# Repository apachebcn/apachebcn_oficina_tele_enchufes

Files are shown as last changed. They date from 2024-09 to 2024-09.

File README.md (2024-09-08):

# apachebcn_oficina_tele_enchufes

Control remoto de enchufes, pensado para la oficina para encender y apagar fácilmente todos los dispositivos.
Incluye proyecto de Kicad para fabricar las placas.

El proyecto consta de 2 placas pcbs.
1 pcb para conectar el arduino a los relés. (yo lo tengo debajo de la mesa, porque no es necesario tener acceso nivisibilidad a esta placa)
1 pcb de interfaz donde están los pulsadores para activar/desactivar los relés, y leds de testigos para saber que relés están encendidos.

Foto de pcb de la interfaz:

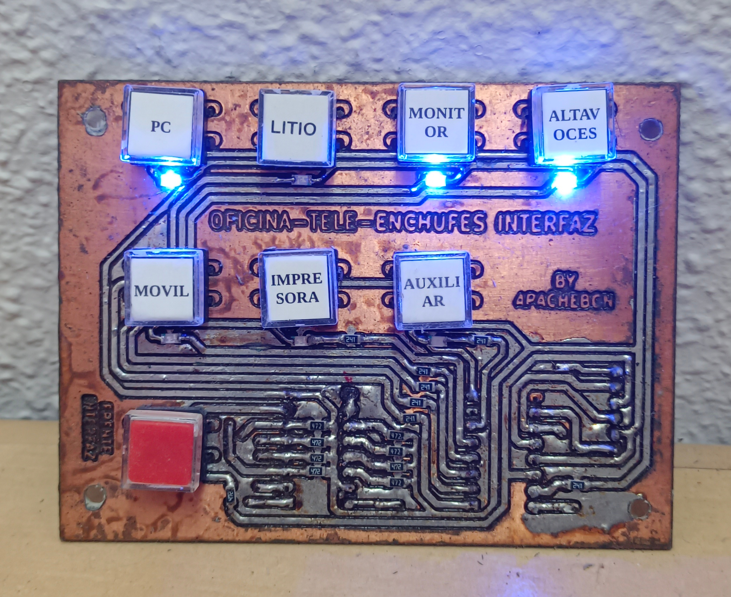
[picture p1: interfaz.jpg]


Foto de pcb de los relés:



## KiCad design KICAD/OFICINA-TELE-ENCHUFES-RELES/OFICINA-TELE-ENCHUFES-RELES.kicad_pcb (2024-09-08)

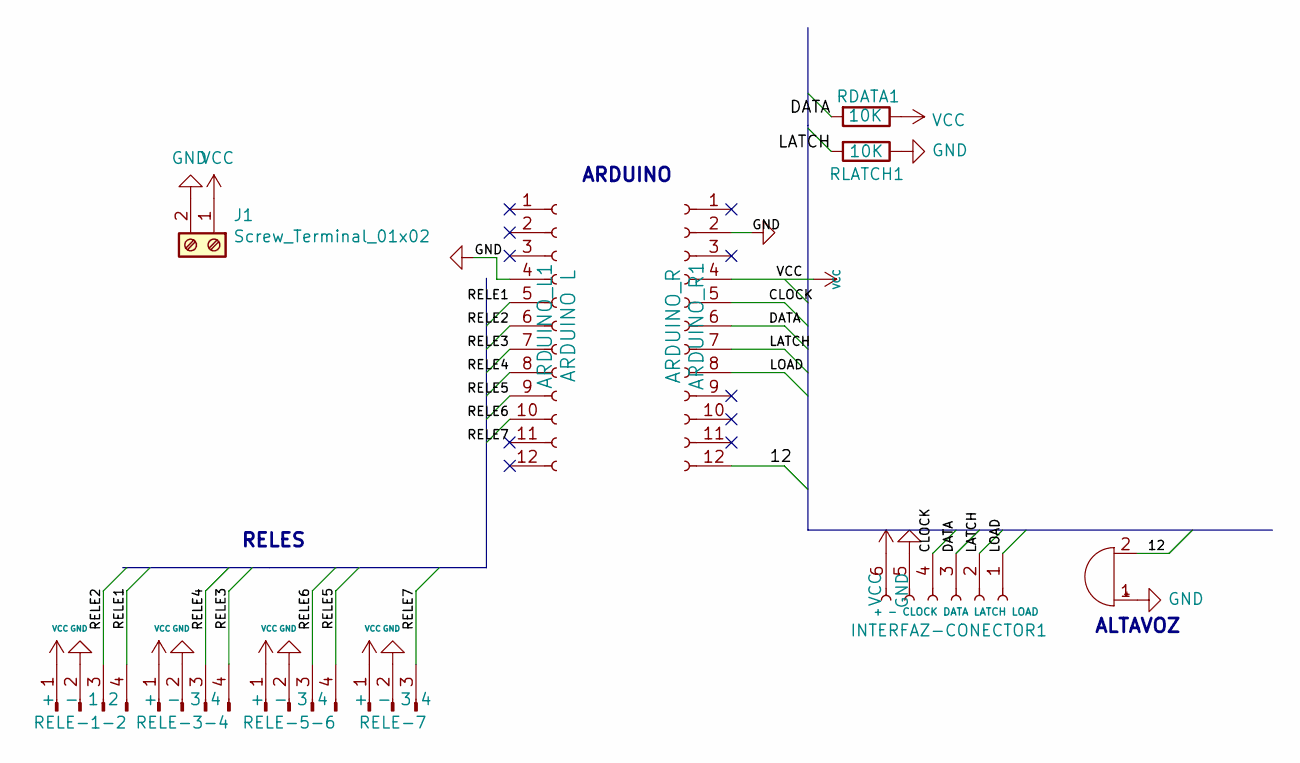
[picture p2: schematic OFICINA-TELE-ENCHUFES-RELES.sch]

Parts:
ARDUINO_L1: ARDUINO L; PinSocket_1x13_P2.54mm_Vertical
ARDUINO_R1: ARDUINO_R; PinSocket_1x13_P2.54mm_Vertical
BUZZER1: SPEAKER; Buzzer_12x9.5RM7.6
INTERFAZ-CONECTOR1: + - CLOCK DATA LATCH LOAD; JST_EH_B6B-EH-A_1x06_P2.50mm_Vertical
J1: Screw_Terminal_01x02; TerminalBlock_bornier-2_P5.08mm
RDATA1: 10K; R_1206_3216Metric
RELE-1-2: + - 1 2; PinHeader_1x04_P2.54mm_Horizontal
RELE-3-4, RELE-5-6: + - 3 4; PinHeader_1x04_P2.54mm_Horizontal
RELE-7: + - 3 4; PinHeader_1x03_P2.54mm_Horizontal
RLATCH1: 10K; R_1206_3216Metric

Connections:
/12: ARDUINO_R1.12, BUZZER1.2 (+)
/CLOCK: ARDUINO_R1.5, INTERFAZ-CONECTOR1.4
/DATA: ARDUINO_R1.6, INTERFAZ-CONECTOR1.3, RDATA1.2
/LATCH: ARDUINO_R1.7, INTERFAZ-CONECTOR1.2, RLATCH1.2
/LOAD: ARDUINO_R1.8, INTERFAZ-CONECTOR1.1
/RELE1: ARDUINO_L1.5, RELE-1-2.4
/RELE2: ARDUINO_L1.6, RELE-1-2.3
/RELE3: ARDUINO_L1.7, RELE-3-4.4
/RELE4: ARDUINO_L1.8, RELE-3-4.3
/RELE5: ARDUINO_L1.9, RELE-5-6.4
/RELE6: ARDUINO_L1.10, RELE-5-6.3
/RELE7: ARDUINO_L1.11, RELE-7.3
GND: ARDUINO_L1.4, ARDUINO_R1.2, BUZZER1.1 (-), INTERFAZ-CONECTOR1.5, J1.2, RELE-1-2.2, RELE-3-4.2, RELE-5-6.2, RELE-7.2, RLATCH1.1
VCC: ARDUINO_R1.4, INTERFAZ-CONECTOR1.6, J1.1, RDATA1.1, RELE-1-2.1, RELE-3-4.1, RELE-5-6.1, RELE-7.1

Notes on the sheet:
ALTAVOZ
RELES
ARDUINO

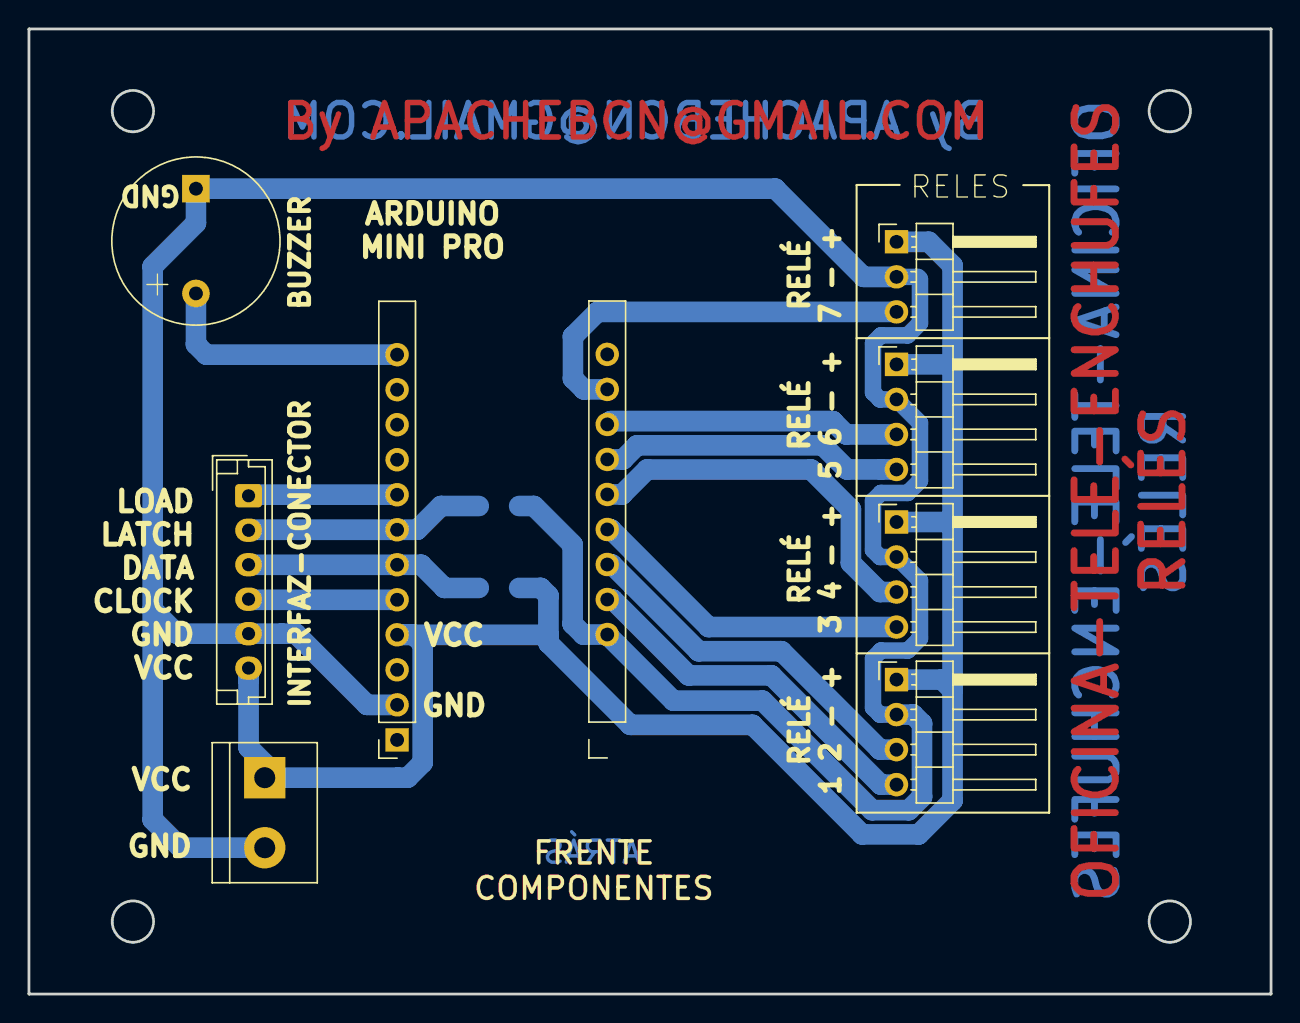
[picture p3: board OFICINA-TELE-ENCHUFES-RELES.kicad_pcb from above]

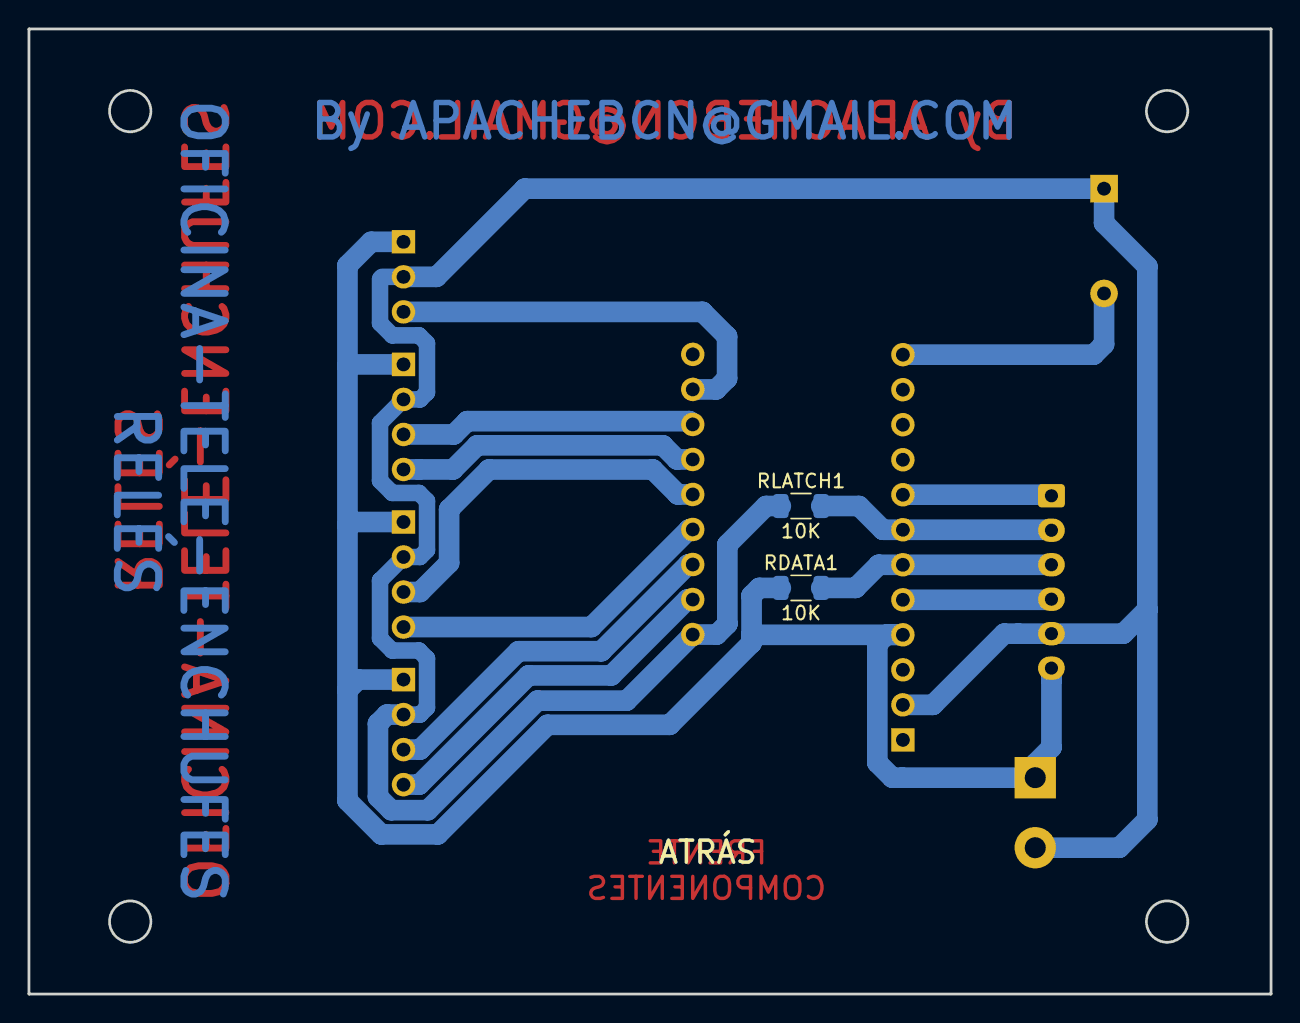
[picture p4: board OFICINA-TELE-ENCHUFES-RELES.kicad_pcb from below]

Board: 2 copper layers, 90.1 x 70.0 mm, 11 parts (2 on the bottom side), 14 nets.

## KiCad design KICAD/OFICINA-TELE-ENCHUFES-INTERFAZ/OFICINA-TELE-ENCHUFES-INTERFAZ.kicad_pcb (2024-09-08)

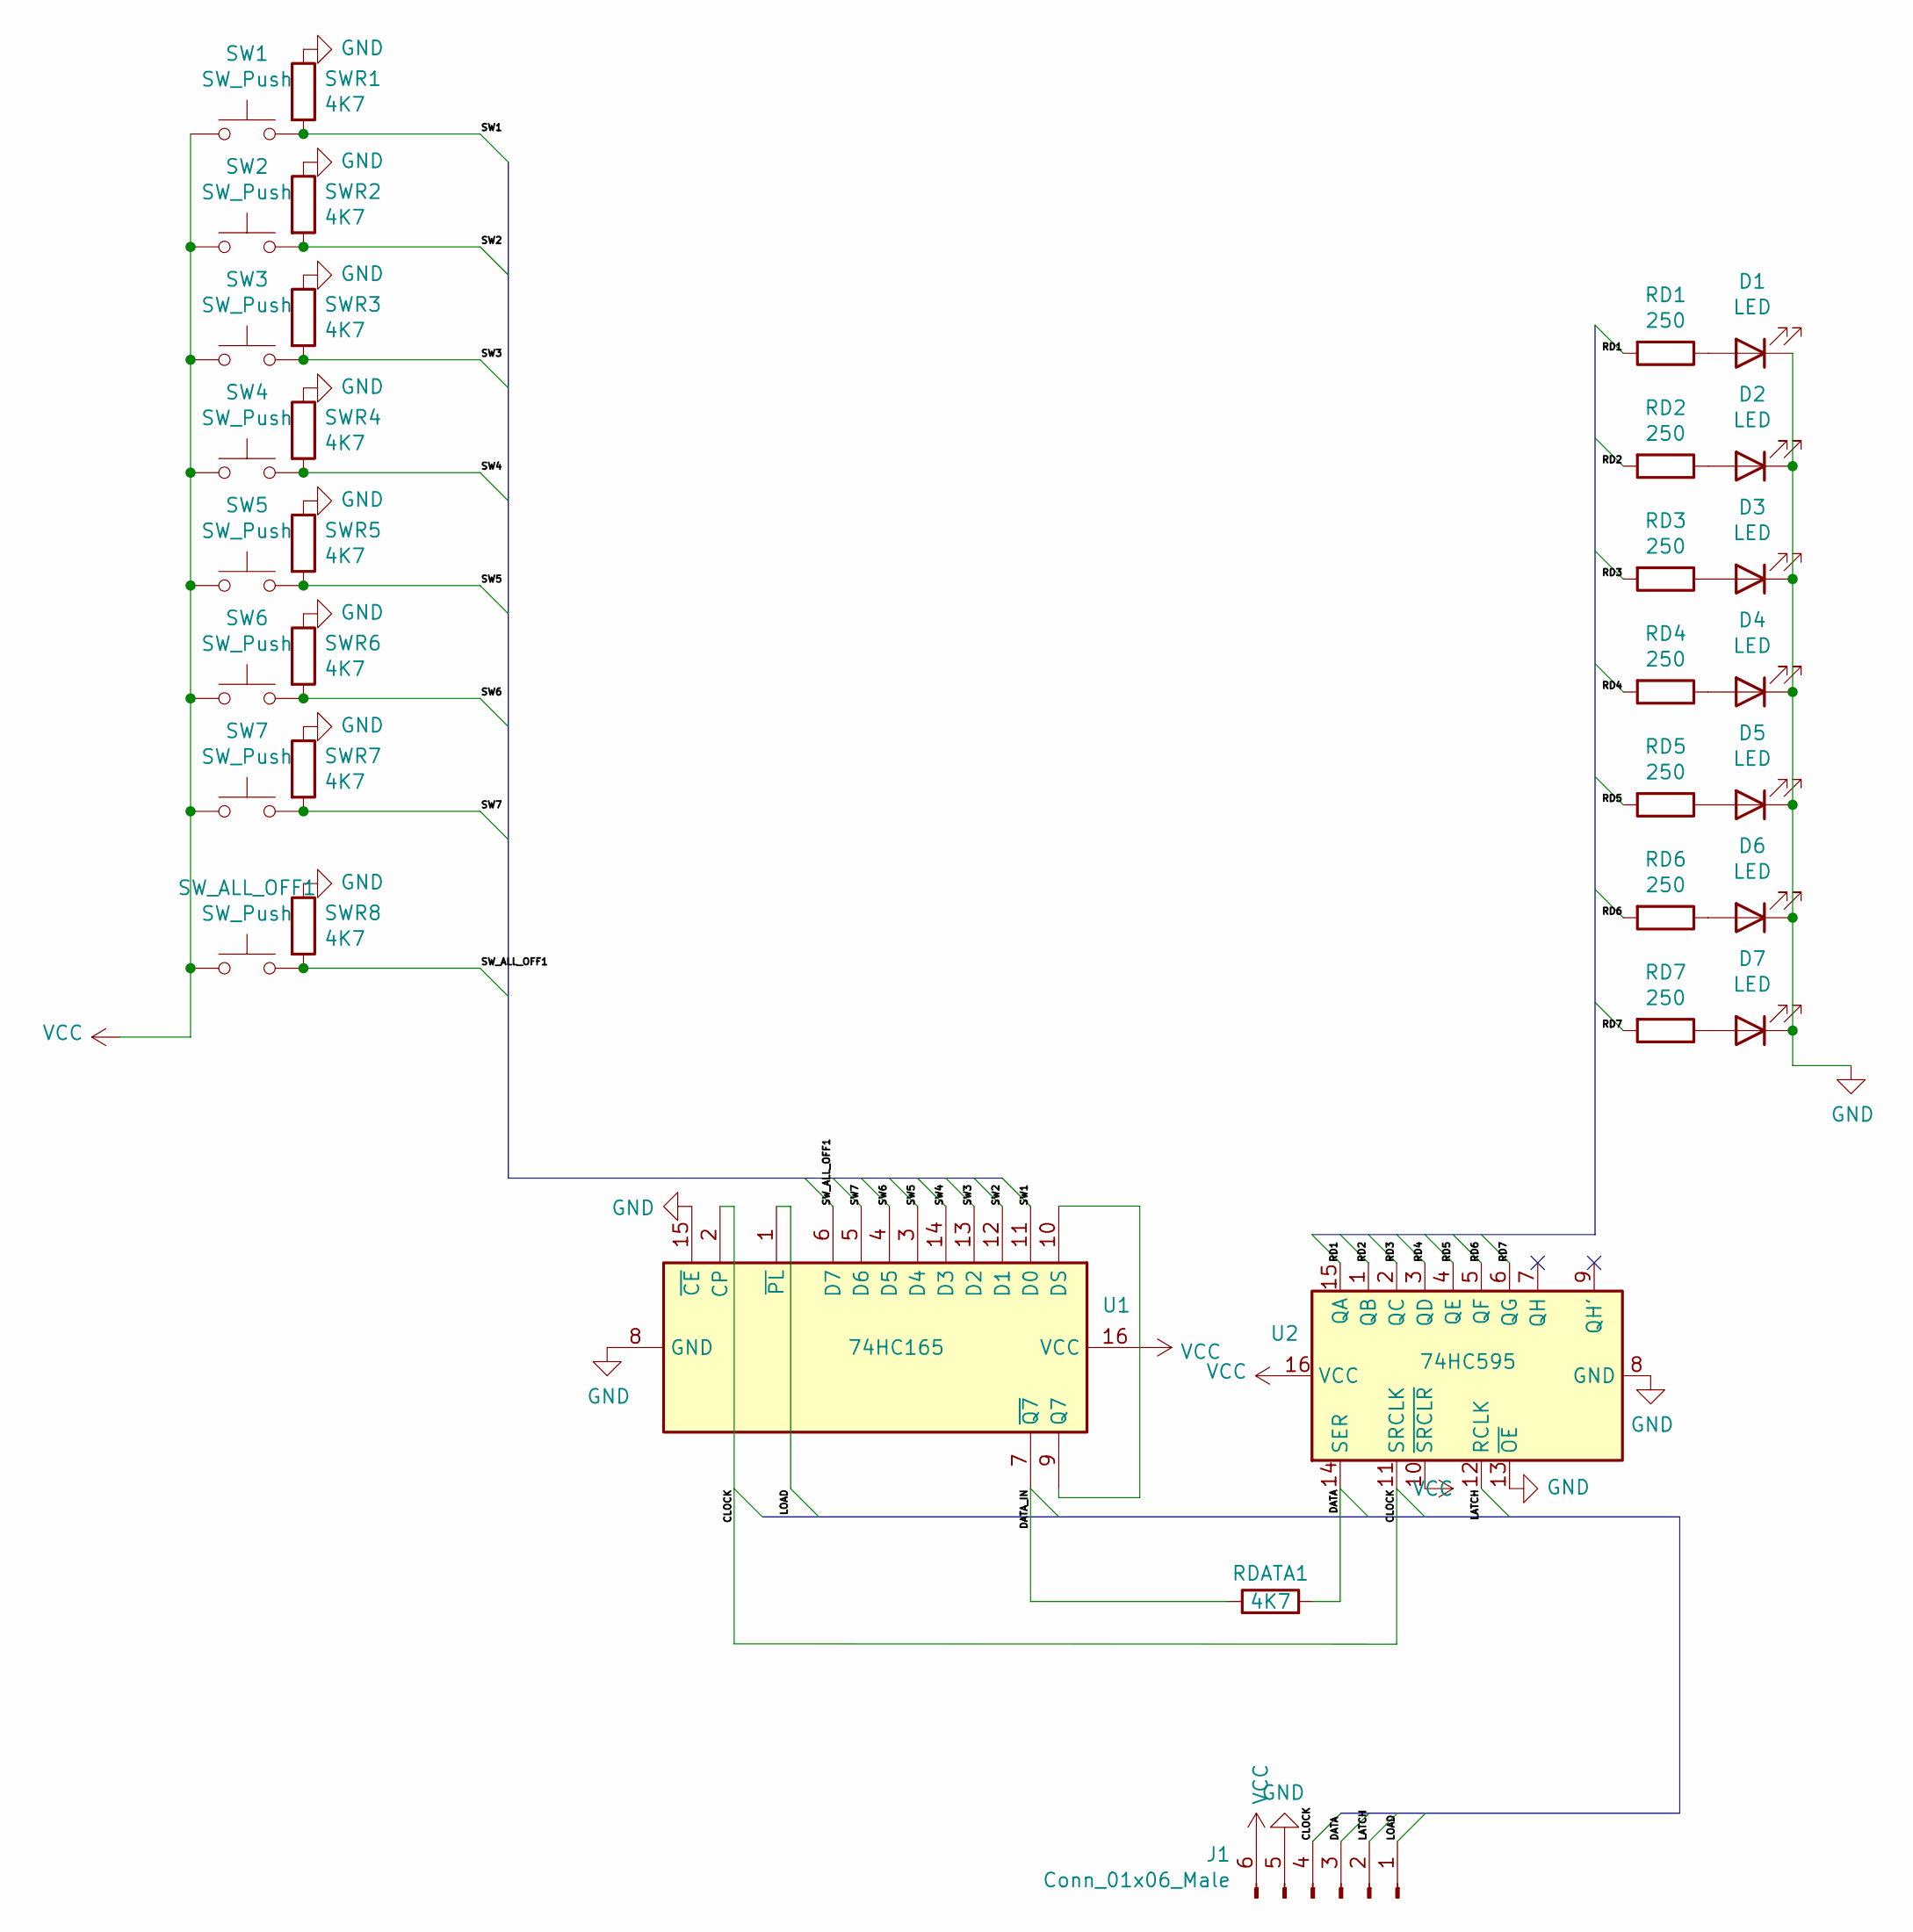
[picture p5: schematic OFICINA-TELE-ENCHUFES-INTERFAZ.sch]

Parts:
D1, D2, D3, D4, D5, D6, D7: LED; D_1206_3216Metric
J1: Conn_01x06_Male; JST_EH_B6B-EH-A_1x06_P2.50mm_Vertical
RD1, RD2, RD3, RD4, RD5, RD6, RD7: 250; R_1206_3216Metric
RDATA1: 4K7; R_1206_3216Metric
SW1, SW2, SW3, SW4, SW5, SW6, SW7: SW_Push; SW_PUSH-12mm
SWR1, SWR2, SWR3, SWR4, SWR5, SWR6, SWR7, SWR8: 4K7; R_1206_3216Metric
SW_ALL_OFF1: SW_Push; SW_PUSH-12mm
U1: 74HC165; DIP-16_W7.62mm
U2: 74HC595; DIP-16_W7.62mm

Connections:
/CLOCK: J1.4, U1.2 (CP), U2.11 (SRCLK)
/DATA: J1.3, RDATA1.2, U2.14 (SER)
/DATA_IN: RDATA1.1, U1.7 (~Q7)
/LATCH: J1.2, U2.12 (RCLK)
/LOAD: J1.1, U1.1 (~PL)
/RD1: RD1.2, U2.15 (QA)
/RD2: RD2.2, U2.1 (QB)
/RD3: RD3.2, U2.2 (QC)
/RD4: RD4.2, U2.3 (QD)
/RD5: RD5.2, U2.4 (QE)
/RD6: RD6.2, U2.5 (QF)
/RD7: RD7.2, U2.6 (QG)
/SW1: SW1.2, SWR1.2, U1.11 (D0)
/SW2: SW2.2, SWR2.2, U1.12 (D1)
/SW3: SW3.2, SWR3.2, U1.13 (D2)
/SW4: SW4.2, SWR4.2, U1.14 (D3)
/SW5: SW5.2, SWR5.2, U1.3 (D4)
/SW6: SW6.2, SWR6.2, U1.4 (D5)
/SW7: SW7.2, SWR7.2, U1.5 (D6)
/SW_ALL_OFF1: SWR8.2, SW_ALL_OFF1.2, U1.6 (D7)
GND: D1.1 (K), D2.1 (K), D3.1 (K), D4.1 (K), D5.1 (K), D6.1 (K), D7.1 (K), J1.5, SWR1.1, SWR2.1, SWR3.1, SWR4.1, SWR5.1, SWR6.1, SWR7.1, SWR8.1, U1.8 (GND), U1.15 (~CE), U2.8 (GND), U2.13 (~OE)
unnamed: D1.2 (A), RD1.1
unnamed: D2.2 (A), RD2.1
unnamed: D3.2 (A), RD3.1
unnamed: D4.2 (A), RD4.1
unnamed: D5.2 (A), RD5.1
unnamed: D6.2 (A), RD6.1
unnamed: D7.2 (A), RD7.1
unnamed: U1.9 (Q7), U1.10 (DS)
VCC: J1.6, SW1.1, SW2.1, SW3.1, SW4.1, SW5.1, SW6.1, SW7.1, SW_ALL_OFF1.1, U1.16 (VCC), U2.10 (~SRCLR), U2.16 (VCC)

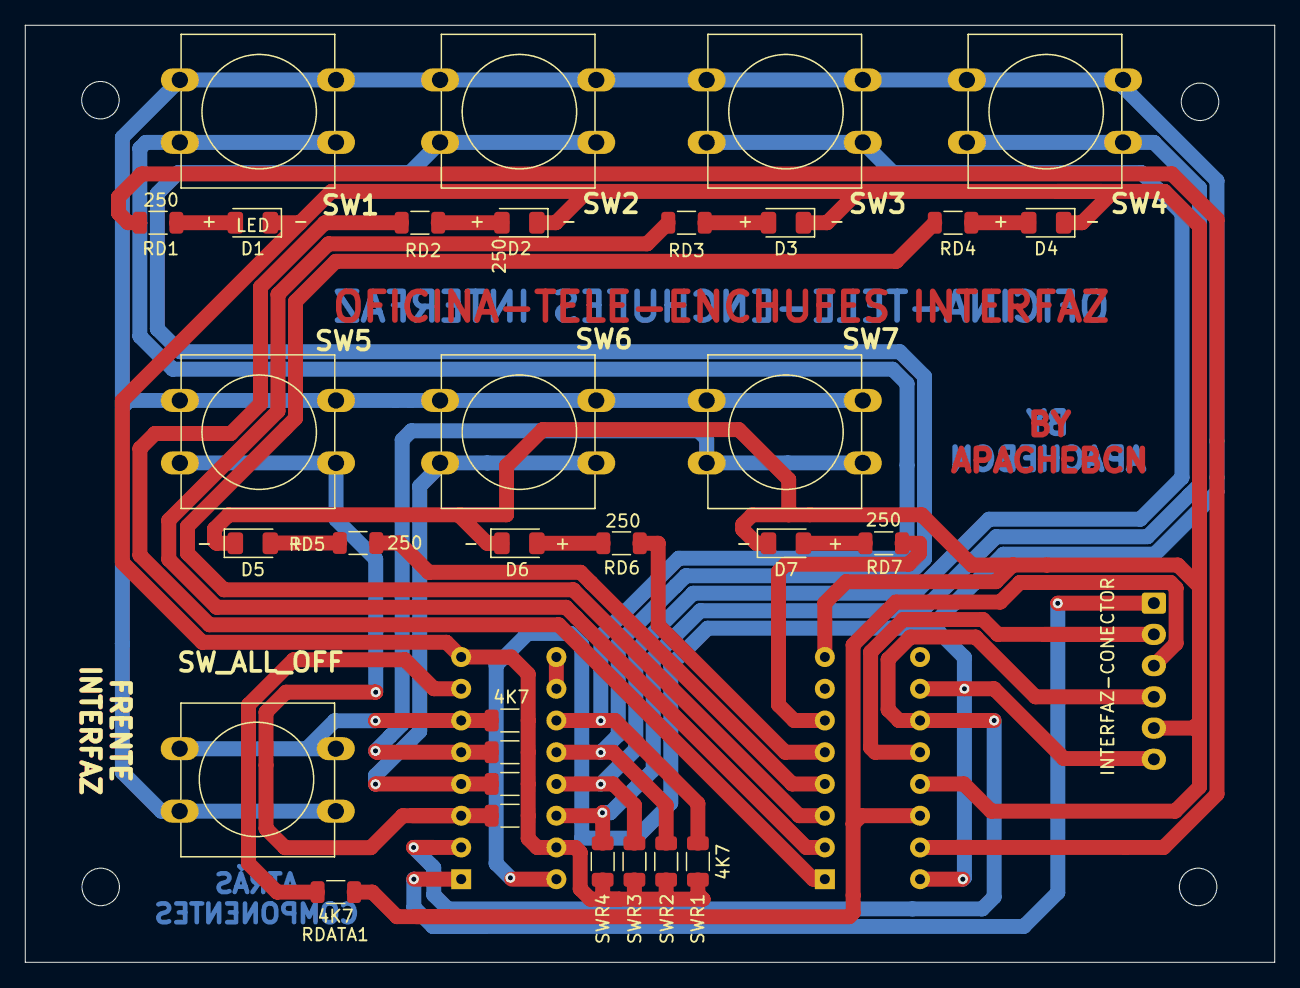
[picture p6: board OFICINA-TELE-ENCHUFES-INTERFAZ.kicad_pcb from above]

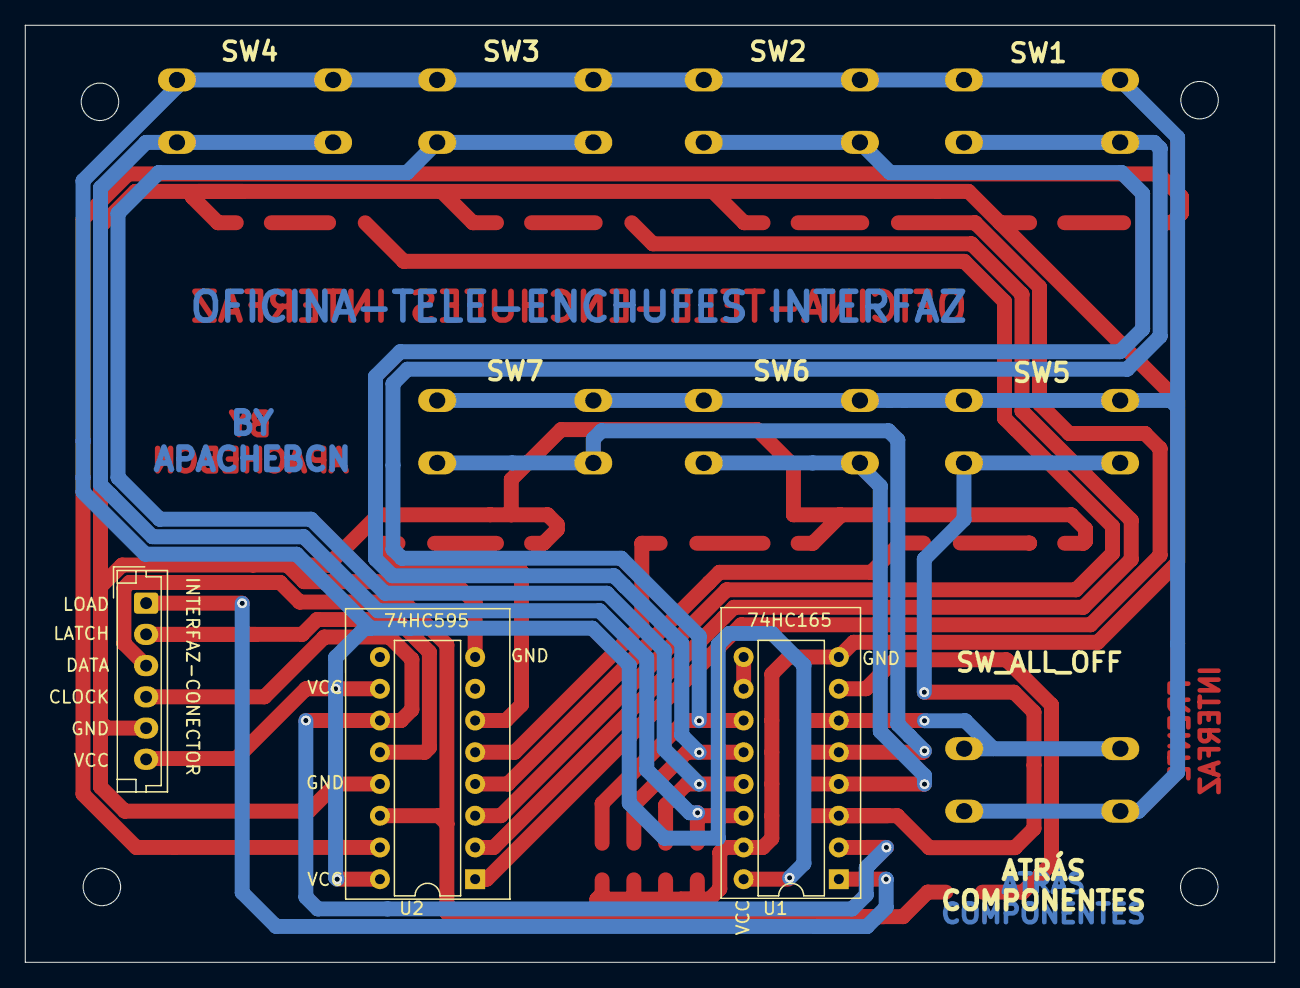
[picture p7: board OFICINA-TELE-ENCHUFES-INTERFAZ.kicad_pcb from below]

Board: 2 copper layers, 100.0 x 75.0 mm, 34 parts (3 on the bottom side), 30 nets.

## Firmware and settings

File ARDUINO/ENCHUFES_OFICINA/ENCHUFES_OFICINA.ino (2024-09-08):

// esquema aplicado: https://forums.parallax.com/uploads/attachments/43798/82270.jpg
//https://forums.parallax.com/discussion/133296/using-a-74hc165-and-a-74hc595-on-4-pins-spin


//poner en latch resistencia de 10Kohmls contra gnd


// Define Connections to 74HC595 

const int PIN_595_LATCH = A1;
/*
    74595 -> ST_CP pin 12
*/

const int PIN_595_AND_165_CLOCK = A3;
/*
    74595 -> SH_CP pin 11
    74165 -> CP pin 2
*/

const int PIN_595_AND_165_DATA = A2;
/*
    74595 -> DS pin 14 
    74165 -> Q7 pin 7
*/

// Define Connections to 74HC165
const int PIN_165_LOAD = A0;
/* 
    74165 -> PL pin 1
*/

const int PIN_RELES[8] = {2, 3, 4, 5, 6, 7, 8, 0};

byte buffer_leds[] = {0, 0, 0, 0, 0, 0, 0};
#define LAST_BIT_FOR_LEDS 7

unsigned long buffer_before_keys_timer[] = {0, 0, 0, 0, 0, 0, 0, 0};
byte buffer_before_keys[] = {0, 0, 0, 0, 0, 0, 0, 0};
byte buffer_keys[] = {0, 0, 0, 0, 0, 0, 0, 0};
#define LAST_BIT_FOR_KEYS 8

byte group_keys_from_key_0[] = {0, 2, 3}; // Para usar con Pc+Monitor+Altavoces
byte group_keys_from_key_1[] = {1, 2, 3}; // Para usar con Portatil+Monitor+Altavoces

const int PIN_BEEPER = 12;

void setup()
{
    pinMode(PIN_595_LATCH, OUTPUT);
    pinMode(PIN_165_LOAD, OUTPUT);
    pinMode(PIN_595_AND_165_CLOCK, OUTPUT);
    pinMode(PIN_595_AND_165_DATA, INPUT);
  
    digitalWrite(PIN_165_LOAD, HIGH);
    digitalWrite(PIN_595_AND_165_CLOCK, LOW);

    pinMode(PIN_BEEPER, OUTPUT);

    for(byte loop_byte_led = 0; loop_byte_led < LAST_BIT_FOR_LEDS; loop_byte_led++)
    {
        pinMode(PIN_RELES[loop_byte_led], OUTPUT); //Setea el pin de cada relé
        digitalWrite(PIN_RELES[loop_byte_led], 1); //Apaga el estado de cada relé para iniciar con todos apagados
    }

    // Serial.begin(115200);
    ledsTest();
}


void loop() 
{

    readKeys();
    // for (byte loop_byte_led=0; loop_byte_led < LAST_BIT_FOR_LEDS; loop_byte_led++)
    // {
        // buffer_leds[loop_byte_led] = buffer_keys[loop_byte_led];
        // Serial.print(buffer_keys[loop_byte_led]);
    // }
    // Serial.println();

    flushLeds();
    flushReles();

    for (byte loop_byte_key=0; loop_byte_key < LAST_BIT_FOR_KEYS; loop_byte_key++)
    {
        if (buffer_keys[loop_byte_key] == 1)
        {
            if (buffer_before_keys_timer[loop_byte_key] == 0) buffer_before_keys_timer[loop_byte_key] = millis();
        }
        else
        {
            if (buffer_before_keys[loop_byte_key] == 1 && buffer_keys[loop_byte_key] == 0)
            {
                if ((millis()-buffer_before_keys_timer[loop_byte_key]) > 400)
                {
                    if (key_long_action(loop_byte_key) == 1)
                    {
                        beep();
                        delay(100);
                        beep();
                    }
                }
                else
                {
                    if (key_action(loop_byte_key) == 1)
                    {
                        beep();
                    }
                }
                buffer_before_keys_timer[loop_byte_key] = 0;
            }
        }
        buffer_before_keys[loop_byte_key] = buffer_keys[loop_byte_key];
    }
}

void ledsTest()
{
    byte loop_byte_led = 0;
    byte led_byte_clear = 0;
    for(loop_byte_led = 0; loop_byte_led < LAST_BIT_FOR_LEDS; loop_byte_led++)
    {
        for (led_byte_clear = 0; led_byte_clear < LAST_BIT_FOR_LEDS; led_byte_clear++) { buffer_leds[led_byte_clear] = 0; }
        buffer_leds[loop_byte_led] = 1;
        flushLeds();
        beep();
    }
    for (led_byte_clear = 0; led_byte_clear < LAST_BIT_FOR_LEDS; led_byte_clear++) { buffer_leds[led_byte_clear] = 1; }
    for (led_byte_clear = 0; led_byte_clear < LAST_BIT_FOR_LEDS; led_byte_clear++) { buffer_leds[led_byte_clear] = 0; }
}

void readKeys()
{
    byte chip_bit;
    delay(5);
    pinMode(PIN_595_AND_165_DATA, INPUT);
    digitalWrite(PIN_165_LOAD, HIGH);
    delay(5);
    digitalWrite(PIN_165_LOAD, LOW);
    digitalWrite(PIN_165_LOAD, HIGH);
    delay(5);

    byte keys = shiftIn(PIN_595_AND_165_DATA, PIN_595_AND_165_CLOCK, LSBFIRST);
    for(byte loop_byte_key = 0; loop_byte_key < LAST_BIT_FOR_KEYS; loop_byte_key++)
    {
        switch(loop_byte_key)
        {
            case 0: chip_bit = 6; break;
            case 1: chip_bit = 5; break;
            case 2: chip_bit = 4; break;
            case 3: chip_bit = 3; break;
            case 4: chip_bit = 2; break;
            case 5: chip_bit = 1; break;
            case 6: chip_bit = 0; break;
            case 7: chip_bit = 7; break;
            case 8: chip_bit = 8; break;
        }
        buffer_keys[chip_bit] = 1;
        if (bitRead(keys, loop_byte_key)) buffer_keys[chip_bit] = 0;
    }
}

void flushLeds()
{
    byte leds_value = 0;
    byte chip_bit = 0;
    delay(5);
    pinMode(PIN_595_AND_165_DATA, OUTPUT);
    for (byte loop_byte_led = 0; loop_byte_led < LAST_BIT_FOR_LEDS; loop_byte_led++)
    {
        switch(loop_byte_led)
        {
            case 0: chip_bit = 6; break;
            case 1: chip_bit = 5; break;
            case 2: chip_bit = 4; break;
            case 3: chip_bit = 3; break;
            case 4: chip_bit = 2; break;
            case 5: chip_bit = 1; break;
            case 6: chip_bit = 0; break;
        }
        leds_value <<= 1;
        bool real_value = buffer_leds[chip_bit];
        leds_value |= real_value;
    }
    digitalWrite(PIN_595_LATCH, LOW);
    shiftOut(PIN_595_AND_165_DATA, PIN_595_AND_165_CLOCK, MSBFIRST, leds_value);
    digitalWrite(PIN_595_LATCH, HIGH);
}

void flushReles()
{
    // Nos basamos en el buffer de leds para setear cada relé
    for(byte loop_byte_led = 0; loop_byte_led < LAST_BIT_FOR_LEDS; loop_byte_led++)
    {
        digitalWrite(PIN_RELES[loop_byte_led], !buffer_leds[loop_byte_led]);
    }
}

void beep()
{
    digitalWrite(PIN_BEEPER, 1);
    delay(5);
    digitalWrite(PIN_BEEPER, 0);
}

bool key_action(byte byte_key)
{
    byte loop_byte_led = 0;
    if (byte_key == 7)
    {
        for(loop_byte_led = 0; loop_byte_led < LAST_BIT_FOR_LEDS; loop_byte_led++)
        {
            buffer_leds[loop_byte_led] = 0;
        }
        return 1;
    }
    else
    {
        buffer_leds[byte_key] = !buffer_leds[byte_key];
    }
    return 1;
}

bool key_long_action(byte byte_key)
{
    byte *group_keys;
    switch(byte_key)
    {
        case 0:
            group_keys = group_keys_from_key_0;
            break;
        case 1:
            group_keys = group_keys_from_key_1;
            break;
        default:
            return 0;
    }

    for (byte loop = 0; loop < sizeof(group_keys)+1; loop++)
    {
        buffer_leds[group_keys[loop]] = 1;
    }
    return 1;
}
